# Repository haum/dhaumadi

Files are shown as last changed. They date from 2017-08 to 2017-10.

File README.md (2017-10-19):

# dhaumadi
Code of dHaumadi project

The dhaumadi project is a Simon Says game engineered to be set up in a wooden geodesic
dome. The game is designed to force collaboration between players to replay the sequence
by using a human-sized dome that nobody can master alone.

## Installing & Running

To setup a new instance:

1. Install Python 3.6+
2. Install Fluidsynth and a soundfont
3. Install pySerial
4. Clone this repo

	$ git clone https://github.com/haum/dhaumadi.git
	$ cd dhaumadi
	$ git submodule init
	$ git submodule update

To run the game:

1. Start fluidsynth in server mode:

	$ fluidsynth --server -a alsa /usr/share/sounds/sf2/FluidR3_GM.sf2

2. Start the serial bridge and pipe its output to the game script:

	$ ./dhaumadi.py | ./game/game.py

More info (fr) : https://pad.aumbox.fr/p/20170802_Teriaki2017

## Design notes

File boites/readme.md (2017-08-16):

contenu du repertoire

cut_panel.dxf		patron de decoupe d'une boite avec sa face avant (carre)

cut_panel_dual.dxf	patron de decoupe de deux boite sans face avant

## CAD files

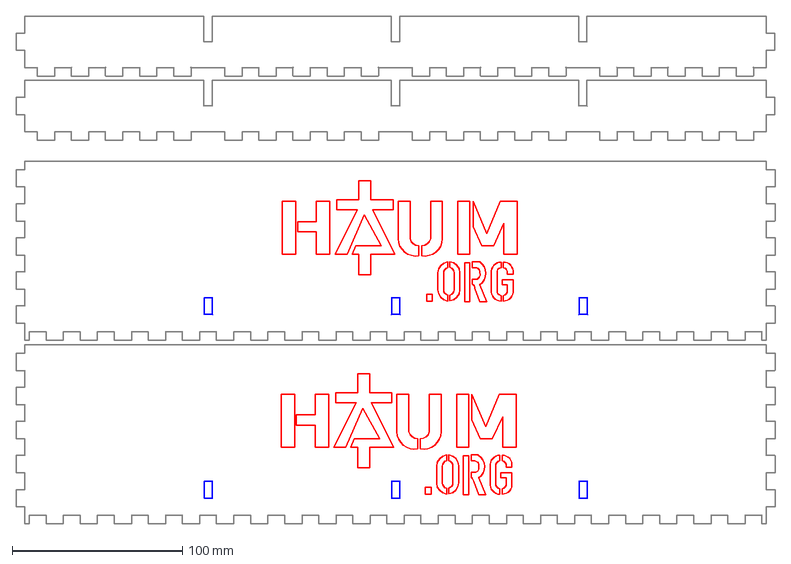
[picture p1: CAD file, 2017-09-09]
boites/tray_box2.dxf
445.3 x 298.0 mm

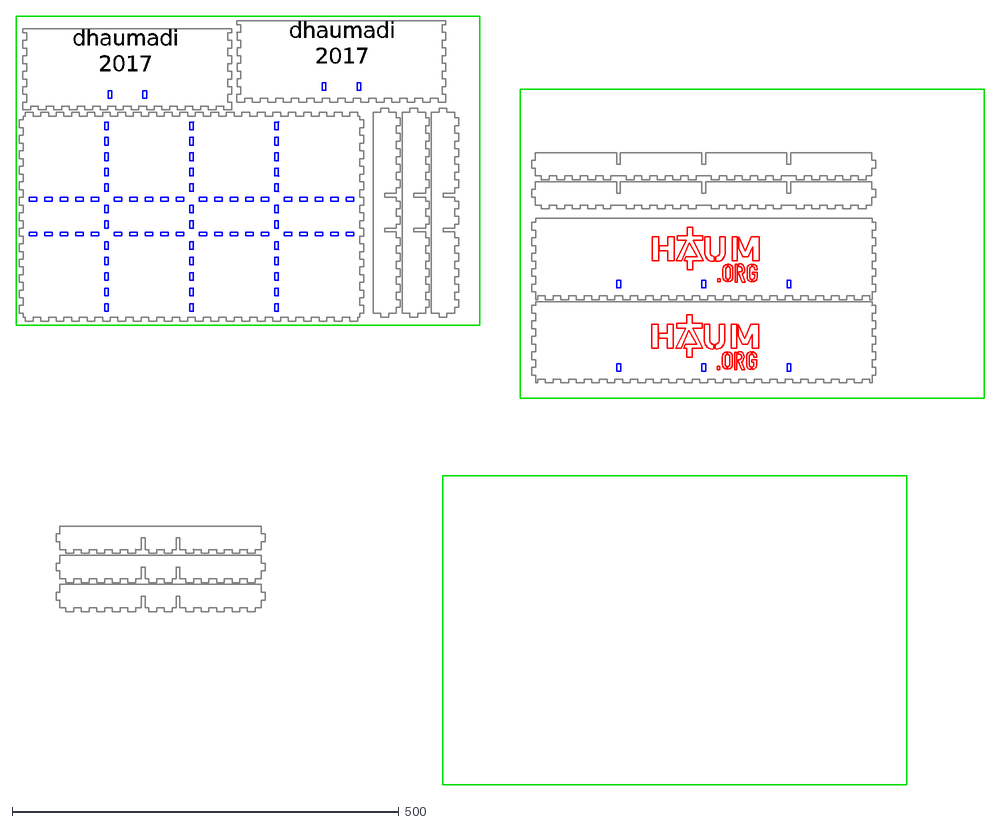
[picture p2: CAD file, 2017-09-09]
boites/boxtray.dxf
dhaumadi 2017

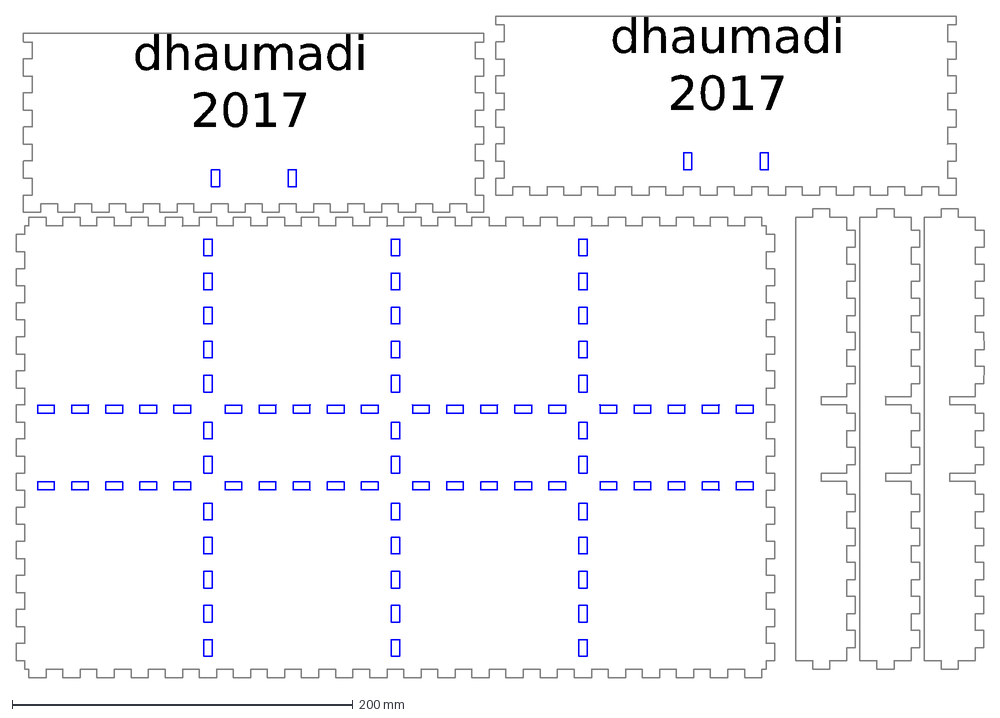
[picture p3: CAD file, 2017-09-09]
boites/tray_box1.dxf
dhaumadi 2017

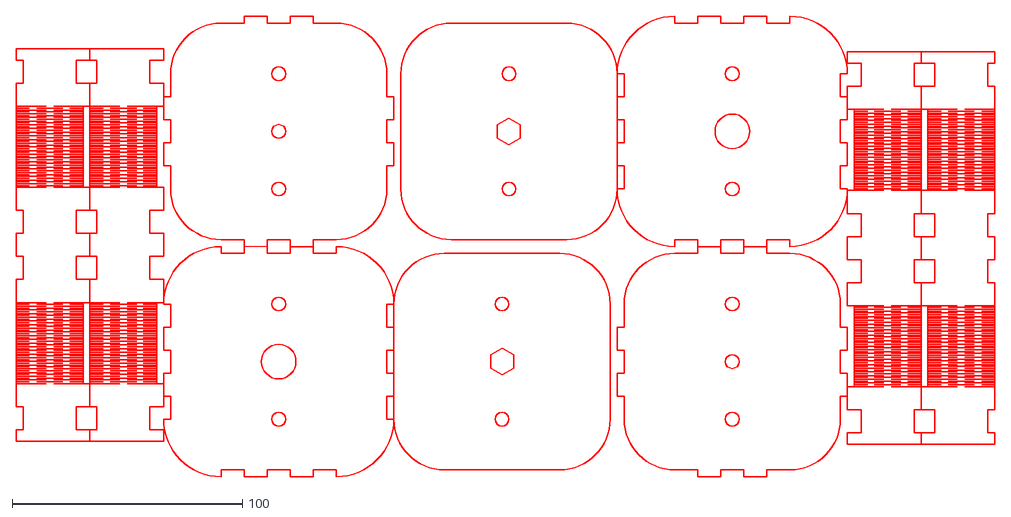
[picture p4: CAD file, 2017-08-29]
boites/cut_panel_dual.dxf
425.0 x 200.0

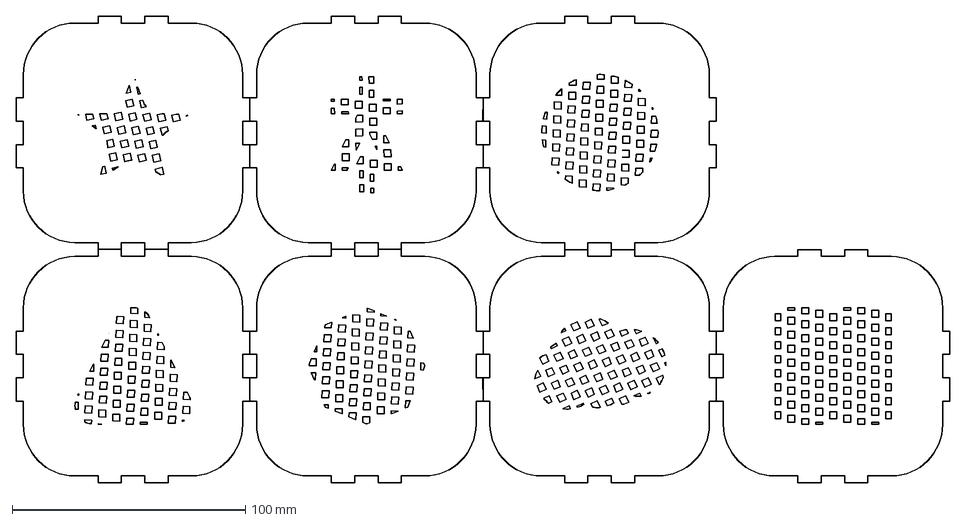
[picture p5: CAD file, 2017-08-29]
boites/cut_panel_grilles.dxf
400.0 x 200.0 mm

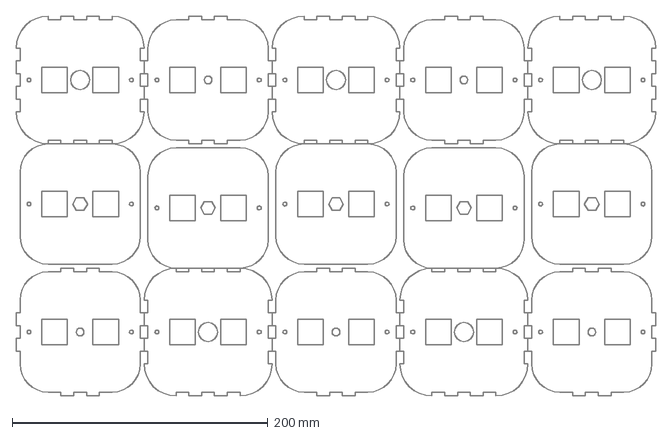
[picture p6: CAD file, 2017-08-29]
boites/cut_panel_backs.dxf
500.0 x 297.0 mm

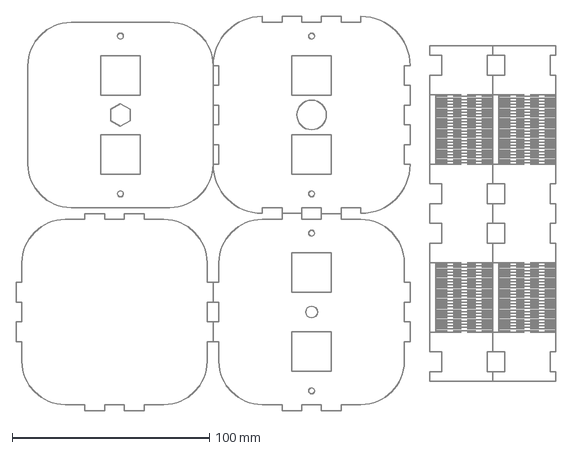
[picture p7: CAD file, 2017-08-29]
boites/cut_panel_wemos.dxf
274.0 x 200.0 mm

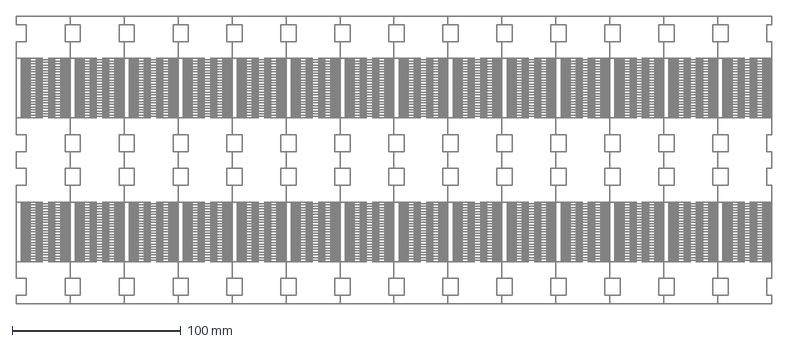
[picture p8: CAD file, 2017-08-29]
boites/cut_cotes.dxf
448.0 x 170.4 mm

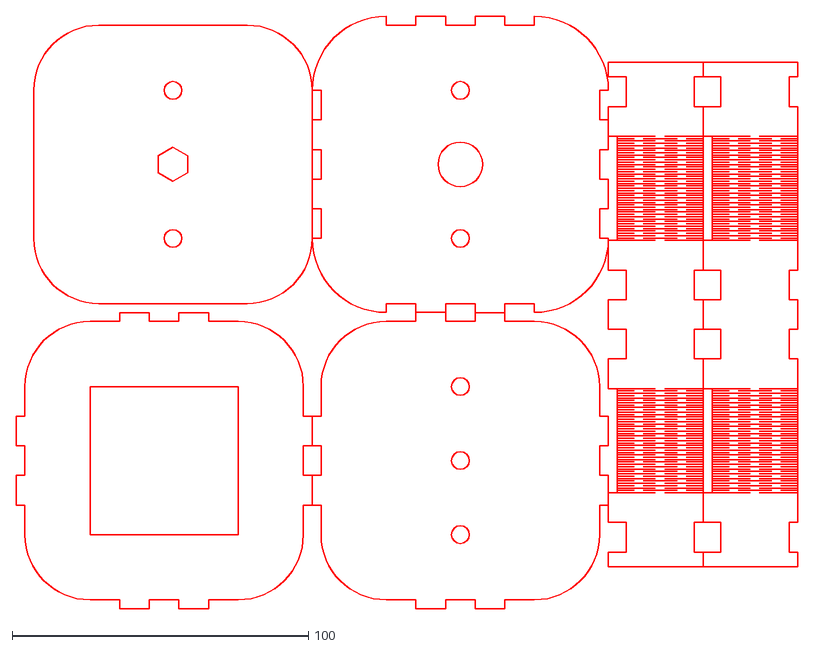
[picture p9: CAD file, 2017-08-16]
boites/cut_panel.dxf
264.0 x 200.0

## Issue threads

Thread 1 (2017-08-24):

modifs pour que ca marche sur raspberry (en urgence)

jblb, 2017-08-24:
upgrade python en 3.6 ( compile)
ajouter la soudnfont a la ligne de commande de fluidsynth
installation de pyserial pour python 3.6
modif de la ligne de commande du service dhaumadi pour utiliser python 3.5

jblb, 2017-08-24:
mettre le bouton "ON" sur les enceintes

jblb, 2017-08-24:
intaller la commande de jeu dans un fichier bash appelé par le service au démarrage car pas de prise en compte du | par celle ci

jblb, 2017-08-28:
intaller la commande de jeu dans un fichier bash appelé par le service au démarrage car pas de prise en compte du | par celle ci

Matael, 2017-09-03:
C'est règlé ça hein ? C'était pour Teriaki uniquement ?

jblb, 2017-09-03:
python 3.6 c'est OK
ajouter la soudnfont a la ligne de commande de fluidsynth c'est fait
le fichier bach c'est le start.sh c'est donc fait

Matael, 2017-09-03:
Donc on ferme !

jblb, 2017-09-03:
cette issue était faite pour garder une trace de ce que l'on faisais et pourquoi elle peut etre fermée ;-)

Matael, 2017-09-03:
Au besoin, Github a ajouté l'outil "Projets" qui permet de faire des kanban. Ça me semblerait plus pertinent pour ce genre de trucs :)

JackDesBwa, 2017-09-03:
L'installation de l'environnement sur la raspberry pi est automatisée via puppet.
Ces modifications ne sont pas dans cette procédure => réouvert

Matael, 2017-09-03:
Tiens, on a pas le/les manifest(s) Puppet => il faudrait les ajouter ici.

jblb, 2020-03-13:
quelqu'un sais ou il faut que j'aille chercher le/les manifest(s) Puppet sur la carte SD qui etait dans le pi que je mette ça là

neomilium, 2020-03-16:
Je pense qu'ils sont uniquement sur le serveur du HAUM

Closed 2020-03-19.

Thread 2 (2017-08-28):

connecter les LEDs directement sur le raspberry pi

jblb, 2017-08-28:
plusieurs fois lors de la présentation de la structure aux siestes Teriaki la connexion wifi entre le raspberry et les led est tombée et a donc interrompu le jeu...
l'idée c'est donc de piloter directement les leds avec le pi, par exemple avec cette bibliothèque:  https://github.com/jgarff/rpi_ws281x

Matael, 2017-09-03:
La librairie que linke @jblb demande de blacklister `snd_bcm2835` ce qui me semble un peu compremettre le côté "son" du projet. La discussion sur IRC a mené a :
- on peut utiliser une interface externe pour le son
- ça a été testé sur un pi0 mais pas sur un pi3 -> a tester rapidement

Ça impliquera de modifier aussi `PadsManager` dans game/game.py ligne 111

jblb, 2017-09-03:
je fait marcher le jeux sur un pi0 avec une interface son externe sans avoir rien modifier au code

Matael, 2017-09-03:
Ah ben si t'arrives à passer de "on utilise des laumios" à "on passe par SPI" sans toucher au code, je te paye une 🍺  !

jblb, 2017-09-03:
j'avais pris ta demande modif de game/game.py ligne 111 et suivante pour la gestion du son :-(
effectivement qu'il faudra la modifier si on passe par SPI pour commander les leds

JackDesBwa, 2017-09-03:
Je n'ai pas testé la bibliothèque, mais son Readme indique explicitement qu'elle peut utiliser le SPI et que dans ce cas, il n'y a pas besoin de couper le son.

J'avais étudié la faisabilité via SPI et les indices du Readme suggèrent que l'auteur est arrivé à la même conclusion que moi. De plus, d'autres passages indiquent  qu'il a effectivement testé avec succès.

Je suggère que nous utilisions cette voie pour éviter d'ajouter une prothèse de voix là où elle est manifestement superflue.

JackDesBwa, 2017-09-03:
Techniquement, il est possible de ne pas modifier le code de game.py pour faire fonctionner la nouvelle solution. Cependant, je n'exposerai pas la méthode tordue de crainte qu'elle ne soit  envisagée comme viable.

Matael, 2017-09-03:
Je la veux bien quand même.... oh. Tu penses à... "ne pas modifier le code **de game.py**" : ça sent le truc *vraiment* dégueu là, genre faire importer un "Laumio" un peu modifié... pas beau.

JackDesBwa, 2017-09-06:
Je parlais plus généralement de ne pas modifier le code existant.
Mais non, on n'expose pas en public des bricolages pareils.

Matael, 2017-10-19:
Bon, là, on a un truc qui marche entièrement sur Raspberry pi. Je ferme cette issue !

Closed 2017-10-19.

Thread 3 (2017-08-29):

ajouter un son specifique au debut de la sequence

jblb, 2017-08-29:
en plus de l'animation lumineuse jouer un son spécifique au début de la séquence

jblb, 2017-08-29:
done with commit https://github.com/haum/dhaumadi/commit/4169c5bce6f3532b1943c3028d62753fe343114a

Closed 2017-08-29.

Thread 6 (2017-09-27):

Adjust config.txt

Matael, 2017-09-27:
See https://github.com/raspberrypi/linux/issues/2060#issuecomment-306756533

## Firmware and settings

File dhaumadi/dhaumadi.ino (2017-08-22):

const int pins[] = {
  A2, A3, A4, A5, A1, A0, 13
};

void setup() {
  Serial.begin(115200);
  for (auto pin : pins) {
    pinMode(pin, OUTPUT);
    digitalWrite(pin, HIGH);
    pinMode(pin, INPUT);
    digitalWrite(pin, LOW);
  }
}

int getValue() {
  int value = 0;
  int v = 1;
  for (auto pin : pins) {
    if (digitalRead(pin))
      value |= v;
    v <<= 1;
  }
  return value;
}

void loop() {
  const int dly = 500;
  int idx_a_zero = 0;
  for (auto pin_a_zero : pins) {
    pinMode(pin_a_zero, OUTPUT);
    delayMicroseconds(dly);

    int value = getValue();

    digitalWrite(pin_a_zero, HIGH);
    pinMode(pin_a_zero, INPUT);
    digitalWrite(pin_a_zero, LOW);

    Serial.print(idx_a_zero);
    Serial.print(' ');
    Serial.println(value);

    ++idx_a_zero;
  }

  int value = getValue();
  Serial.print("- ");
  Serial.println(value);
  delayMicroseconds(dly);
  delay(50);
}

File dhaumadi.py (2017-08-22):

#!/usr/bin/env python3

import sys
import serial
from collections import defaultdict

inhib = 0
touches = {}
oldgroups = set()
groupstability = 0
laststablegroups = set()
debounce = defaultdict(lambda: [[0, 0], [0, 0], [0, 0], [0, 0], [0, 0], [0, 0], [0, 0]])

ser = serial.Serial('/dev/ttyACM0', 115200)

while True:
  line = ser.readline()
  if line == '':
    break
  if len(line) < 5:
    continue

  # Decode values
  a = str(line).split(' ')
  pad = a[0][-1:]
  nb = (~int(a[1][:-5])) & 0x7F
  values = []
  while nb:
    values.append(nb & 1)
    nb >>= 1
  values = (values + [0] * 7)[:7]

  # Debounce
  debounce_max = 6
  for i, v in enumerate(values):
    debounce[pad][i][0] += v * 2 - 1
    if debounce[pad][i][0] > debounce_max:
      debounce[pad][i][0] = debounce_max
      debounce[pad][i][1] = 1
    elif debounce[pad][i][0] < 0:
      debounce[pad][i][0] = 0
      debounce[pad][i][1] = 0
  value = sum(1<<i for i, j in enumerate(debounce[pad]) if j[1] == 1)

  # Compute groups
  if pad == '-':
    groups = set()
    for pad in touches:
      pads = ''
      i = 1
      value = touches[pad]
      while value > 0:
         if value & 1:
           pads += str(i)
         value >>= 1
         i += 1
      if len(pads) > 1:
        groups.add(pads)
    if groups != oldgroups:
      oldgroups = groups
      groupstability = 0
    else:
      groupstability += 1
      if groupstability == 3 and laststablegroups != groups:
        laststablegroups = groups
        print(' '.join(groups))
        sys.stdout.flush()
    inhib = value
  else:
    value &= ~inhib
    value |= 1<<int(pad)
  touches[pad] = value

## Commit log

2017-07-11 arduino code for Léoké board
2017-07-13 reduce delay in arduino
    It is more noisy, but it is filtered on PC side
2017-08-15 Basic FluidSynthAudio class via tcp
    Connect to fluidsynth shell via tcp socket
    Note: we do not use fluidsynth python library
2017-08-16 patrons de decoupe de la boite
    [cut_panel.dxf, cut_panel_dual.dxf]
2017-08-22 Update decoder with better filtering
2017-08-22 Add init led sequence
2017-08-29 ajout des fichiers dxf des boites led et wemos
    [cut_cotes.dxf, cut_panel_backs.dxf, cut_panel_grilles.dxf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]
2017-08-29 ajout du niveau attein lorsque l'on perd sur la sortie debug
2017-08-29 suppression layer inutile
    [cut_panel_dual.dxf]
2017-09-05 Add raspberrypi box
2017-09-08 add led manager skeleton
2017-09-09 add boxtray design & cut arangement
    [boxtray.dxf, tray_box1.dxf, tray_box2.dxf]
2017-09-27 leds drived by py - 1st try
2017-09-27 quick and durty hack to get leds shine as expected ;-)
2020-03-13 ajust number of leds to Pads configuration (7pads of 4 leds)
